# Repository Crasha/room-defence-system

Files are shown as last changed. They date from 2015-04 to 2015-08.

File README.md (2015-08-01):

# room-defence-system
A Raspberry Pi, a ~~Gertboard~~ Pro Trinket, a Pi Camera for face recognition and a giant Nerf Rifle!

This project works in conjunction with Tony DiCola's Raspberry Pi powered box which uses face recognition with OpenCV to lock and unlock itself. https://github.com/tdicola/pi-facerec-box 

The software depends on a particular hardware setup, which includes a Raspberry Pi camera, GPIO lines connected to buttons and LEDs. The complete system is able to protect a room by checking faces and activating defences when an unrecognised intruder is detected.

Project video on YouTube : https://youtu.be/M46sbWSLWv8 
----

----

## Hardware Setup Summary

Take a look at the [Fritzing diagram](docs/NerfDoor.fzz) to get started.
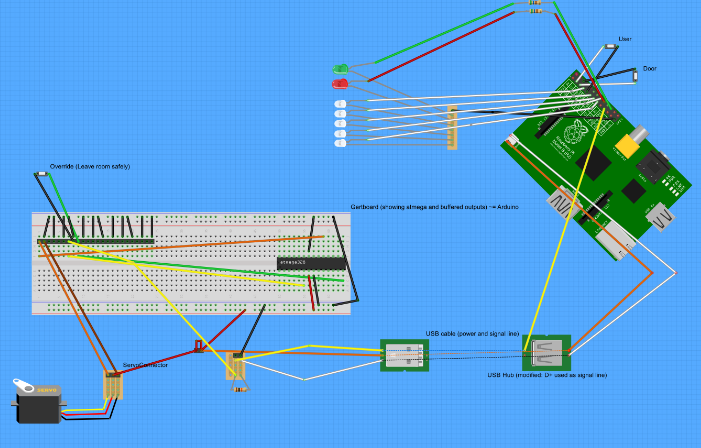
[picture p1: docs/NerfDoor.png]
Fritzing diagram
  
My setup uses a Gertboard to control the servo-motor that pulls the Nerf gun trigger. The Gertboard has many functions - only the relevant bit is represented (by a breadboard) in the Fritzing file.
The ino file in [this folder](servoController/dtServoGun2) is the Atmega328 source code for activating the servo on receipt of a simple 3v3 signal from the Raspberry Pi. The code is suitable for Gertboard, Arduino and similar devices (e.g. Adafruit Pro Trinket 3v 12Mhz).  
It may have been simpler to tape the trigger and just switch power to the gun on and off, but I wanted the challenge of triggering the gun with a servo-motor. My servo is secured next to the Nerf gun trigger using Lego Technic. There are many other approaches that would work equally well.  
[Gordon @ Drogon](https://projects.drogon.net/raspberry-pi/gertboard/arduino-ide-installation-isp/) has produced some excellent material to help you when developing code for the Gertboard's Atmega328 chip.  
[Tony DiCola's pi-facerec-box project pages](https://github.com/tdicola/pi-facerec-box) link to other useful hardware resources. This room-defence-system project uses a different hardware setup, but depends on all the good work Tony put into harnessing OpenCV software for face recognition. Software setup is described below.

## Software Setup Instructions

Start by cloning this project to a convenient location on your Raspberry Pi (V1 model B, B+ or V2), and do a cd into the resulting folder:
```
git clone https://github.com/mech0s/room-defence-system 
cd room-defence-system
```    
Next, clone Tony DiCola's project to create a further sub-folder in which to carry out your face recognition training. The room-defence-system depends on the pi-facerec-box software being in this location.
```
git clone https://github.com/tdicola/pi-facerec-box
cd pi-facerec-box
git reset --hard 10f7f29ba08695c5b6ef79ff2b87503303350644
```
The "git reset" command will ensure you get the particular version (commit) that has been used (the latest commit at the time of writing). If at any point you want to get the very latest version of Tony's project, use "git pull".  

You are now ready to follow [Tony DiCola's instructions](https://learn.adafruit.com/raspberry-pi-face-recognition-treasure-box/software) for building and installing the required software. I built, installed and used OpenCV v2.4.10 successfully in my room-defence-system.

Follow Tony's OpenCV training and configuration guide.  
You can alter pi-facerec-box/config.py to change BUTTON_PIN from 25 to a more appropriate value (BUTTON_PIN = 2 allowed the user-panel button in my setup to be used to trigger training runs)
I also altered the POSITIVE_THRESHOLD value (to 3300.0) in order to make recognition of positive faces more likely.  

Once software has been built, installed, configured and trained you can run the room-defence-system using the script
```
sudo runSystem.sh
```
This could be run in a terminal, but would be best run under a ['screen'](http://www.gnu.org/software/screen/manual/screen.html) session (which can be detached later), or launched from /etc/rc.local at boot, or launched as a system service.

## Speech Output

Not shown on the schematics, but shown at the end of the video: I've added a cheap mobile-phone speaker and modified the Python code to play different sounds or phrases for recognised or unrecognised faces, or when no obvious face can be detected.

Here is a one-liner shell function to get Google Translate to speak any text phrase nicely, returning the result as an MP3.
```
speak()  { curl -G --user-agent "Mozilla/5.0" "http://translate.google.com/translate_tts" --data "tl=en" --data-urlencode "q=$1"; }
```

And here is how to use it...
```
speak "You  don't even look human." > sorry.mp3
```

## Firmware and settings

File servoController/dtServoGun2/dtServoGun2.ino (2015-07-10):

int outPin = 13;
int inFiringPin = 4;
int inOverridePin = 8;
//int maxVal = 3100; 
//int minVal = 1100; 

boolean firing = false;
boolean overriding = false;
unsigned int pulseRep = 20000; //=20 ms

//test values for PWM ~ angle
//unsigned int fireAngle = 1000; //times in microseconds
//unsigned int nofireAngle = 18800;

//operational values for PWM ~ angle
unsigned int fireAngle = 2800; //times in microseconds
unsigned int nofireAngle = 2000;

unsigned long fireTime   =    4000000;// four seconds of firing
//unsigned long nofireTime =    2000000;
unsigned long overrideTime = 10000000; //ten seconds to leave room
unsigned long stateTime = 0;

void setup(){
  pinMode(outPin, OUTPUT);
  pinMode(inFiringPin, INPUT);
  digitalWrite(inFiringPin, LOW);  // no pullup : +ive = On, external pull-down
  pinMode(inOverridePin, INPUT_PULLUP);
  digitalWrite(inOverridePin, HIGH);  // switch on == grounded
}

void loop(){
  if ( firing ){
    pulseRep_us ( fireAngle );
  }
  else {
    pulseRep_us ( nofireAngle);
  }
  
  stateTime += pulseRep;

  if (digitalRead(inOverridePin) == LOW ) {
  //if ( false ){
    overriding = true;
    firing = false;
    stateTime = 0;
  }
  if (!overriding && digitalRead(inFiringPin) == HIGH ) {
     firing = true;
     stateTime = 0;
  }
  
  if ( overriding && (stateTime > overrideTime)){
    overriding = false;
    stateTime = 0;
  }
  if ( firing && (stateTime > fireTime) ){
    firing = false;
    stateTime = 0;
  }

}


void pulseRep_us ( unsigned int highT){
   digitalWrite(outPin, HIGH);
  delayMicroseconds( highT );
   digitalWrite(outPin, LOW);
  delayMicroseconds( pulseRep - highT );
}

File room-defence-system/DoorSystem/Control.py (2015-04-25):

'''
Created on 13 Mar 2015

@author: donald.taylor2
'''
from Util import Observer
import threading
from time import sleep
import time

class Controllable(object):
    '''
    classdocs
    '''
    def __init__(self, model):
        self.model = model
    def userButtonPress (self):
        pass
        #print "press"
    def userButtonDown (self):
        pass
    def userButtonUp (self):
        self.model.authRequested()
    def doorOpen (self):
        self.model.doorOpens()
    def doorClose (self):
        self.model.doorCloses()
    def acceptAuth(self):
        self.model.authAccepted()
    def rejectAuth(self):
        self.model.authRejected()
    def failAuth(self):
        self.model.authFailed()
        
class Controller(Observer.Observer):
    def __init__(self, model):
        self.controllable = Controllable(model)
        self.model = model
        self.model.addObserver(self)
    def update(self, observable, arg):
        print observable.currentState

def defpass(): pass
        
class Flasher(threading.Thread):
    def __init__(self):
        threading.Thread.__init__(self )
        self.running = True
        self.reset = False
        self.timeout = time.clock()
        self.stopState2 = defpass 
        #self.lock = threading.Lock()
        self.start()
    def stop(self):
        self.reset = True
        self.running = False
    def flash(self, startState1, stopState1, startState2, stopState2, duration):
        self.startState1 = startState1        
        self.stopState1 = stopState1
        self.startState2 = startState2        
        self.stopState2 = stopState2
        #self.duration = duration
        self.timeout = time.time() + duration
        self.reset = True
    def run(self):
        while self.running :
            if time.time() < self.timeout:
                self.reset = False
            else:
                sleep(0.05)
                self.reset = True
            self.stopState2()
            if self.reset : continue
            self.startState1()
            if self.reset : continue
            sleep(0.2)
            self.stopState1()
            if self.reset : continue
            self.startState2()
            if self.reset : continue
            sleep(0.2)
            
            

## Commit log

2015-05-03 Add Fritzing diagram and ATMEGA328 source code for trigger servo control (Gertboard)
    [NerfDoor.fzz]
2015-06-05 Added audio output, updated fritzing diagram modified: docs/NerfDoor.fzz modified: room-defence-system/DoorSystem/UI.py modified: room-defence-system/StateMachine/__init__.py new file: room-defence-s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
    [NerfDoor.fzz]
2015-07-10 Modify pin allocations to allow replacement of Gertboard with Adafruit Pro-Trinket 3v. modified: docs/NerfDoor.fzz modified: docs/NerfDoor.png new file: docs/Thumbs.db modified: servoController/dtSer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
    [NerfDoor.fzz]
